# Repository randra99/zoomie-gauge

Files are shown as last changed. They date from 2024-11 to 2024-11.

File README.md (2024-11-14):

# Zoomie Gauge
Zoomie Gauge was created as an effective DIY way of monitoring engine vitals, with the idea that visible alerts are most effective at preventing engine damage as compared to traditional gauges in motorsport applications.

Gauge GIF Gauge GIF

At the moment this has been developed and tested on an NC Mazda MX-5/Miata, however, given the right CAN frames this can be extended to virtually any CAN enabled vehicle.

## Hardware needed:
 - [Arduino UNO board](https://store.arduino.cc/products/arduino-uno-rev3)
 - [1.28 inch LCD Module](https://www.waveshare.com/wiki/1.28inch_LCD_Module)
   - Wiring instructions can be found on the same page
 - [DC to DC Buck Converter](https://www.amazon.co.uk/gp/product/B0823P6PW6/ref=ppx_yo_dt_b_search_asin_title?ie=UTF8&th=1)
 - [MCP2515 CAN Bus Module](https://www.amazon.co.uk/gp/product/B086TXSFD8/ref=ppx_yo_dt_b_search_asin_title?ie=UTF8&th=1)
   - Wiring instructions can be found [here](https://github.com/autowp/arduino-mcp2515)
 - [Bosch PST-F 1 Sensor](https://www.bosch-motorsport.com/content/downloads/Raceparts/en-GB/54249355.html)
   - Consult the data sheet for wiring 

### Nice to haves:
 - [Proto Shield](https://thepihut.com/products/arduino-proto-shield-dev-board-2-0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)
   - This will make splicing the connections for both the CAN Bus module and LCD module is a lot easier.
   - Furthermore, as the Arduino cannot measure resistance out of the box, a small circuit is required utilising a 4.7K ohm resistor to allow computation of the resistance based on voltage. Instructions [here](https://projecthub.arduino.cc/xristos_xatz/ohm-meter-with-arduino-uno-5576cd).

## STL Files
Currently included in `stl-files` is the stl of the screen mount, this will make it easier to mount the screen to the desired surface using double-sided tape. The centre is left empty to allow placing over an existing gauge once the needle is removed.

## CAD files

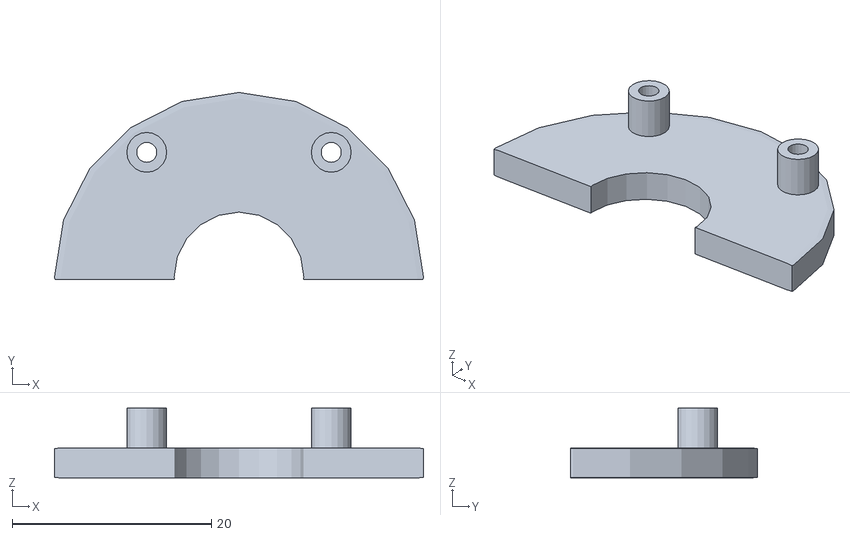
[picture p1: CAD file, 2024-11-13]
stl-files/DisplayMount.stl
37.0 x 18.8 x 7.00

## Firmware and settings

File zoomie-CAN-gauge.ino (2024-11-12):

#include "SPI.h"
#include "Adafruit_GFX.h"
#include "Adafruit_GC9A01A.h"
#include "CAN.h"
#include <math.h>

// Define pins for display interface. You'll probably need to edit this for
// your own needs:

#if defined(ARDUINO_SEEED_XIAO_RP2040)

// Pinout when using Seed Round Display for XIAO in combination with
// Seeed XIAO RP2040. Other (non-RP2040) XIAO boards, any Adafruit Qt Py
// boards, and other GC9A01A display breakouts will require different pins.
#define TFT_CS D1 // Chip select
#define TFT_DC D3 // Data/command
#define TFT_BL D6 // Backlight control

#else // ALL OTHER BOARDS - EDIT AS NEEDED

// Other RP2040-based boards might not have "D" pin defines as shown above
// and will use GPIO bit numbers. On non-RP2040 boards, you can usually use
// pin numbers silkscreened on the board.
#define TFT_DC  7
#define TFT_CS 10
// If display breakout has a backlight control pin, that can be defined here
// as TFT_BL. On some breakouts it's not needed, backlight is always on.

#endif

// Display constructor for primary hardware SPI connection -- the specific
// pins used for writing to the display are unique to each board and are not
// negotiable. "Soft" SPI (using any pins) is an option but performance is
// reduced; it's rarely used, see header file for syntax if needed.
Adafruit_GC9A01A tft(TFT_CS, TFT_DC);

int water_temp = 0;
int oil_pressure = 0;
int oil_temp = 0;
int rpm = 0;

int last_water_temp = -1;
int last_oil_pressure = -1;
int last_oil_temp = -1;

int no_water_temp = 0;
bool no_rpm = true;
bool warning_on = false;

void write_num(int x, int y, int size, int num, int colour=WHITE)
{
  if(num < 0)
  {
    x=x-15;
    if(num < -99)
      x=x-15;
    if(num > -10)
      x=x+15;
  }
  else
  {
    if(num < 10)
      x=x+15;
    if(num > 99)
      x=x-15;
  }
  tft.setTextColor(colour);
  tft.setCursor(x,y);
  tft.setTextSize(size);
  tft.println(String(num));
}

void write_none(int x, int y, int size, int colour=WHITE)
{
  tft.setTextColor(colour);
  tft.setCursor(x,y);
  tft.setTextSize(size);
  tft.println("XX");
}

void write_values(int water_temp, int oil_pressure, int oil_temp, bool force_write=false)
{
  if(last_water_temp!=water_temp || force_write)
  {
    tft.fillRect(92, 13, 70, 35, BLACK);
    write_num(92,13,5,water_temp);
    last_water_temp = water_temp;
  }
  if(last_oil_pressure!=oil_pressure || force_write)
  {
    tft.fillRect(125, 102, 70, 35, BLACK);
    write_num(125,102,5,oil_pressure);
    last_oil_pressure = oil_pressure;
  }
  if(last_oil_temp!=oil_temp || force_write)
  {
    tft.fillRect(90, 188, 70, 35, BLACK);
    write_num(90,188,5,oil_temp);
    last_oil_temp = oil_temp;
  }
}

void write_text(int x, int y, int size, char* text, int colour=WHITE)
{
  tft.setTextColor(colour);
  tft.setCursor(x,y);
  tft.setTextSize(size);
  tft.write(text);
}

void display_water_warning()
{
  tft.fillScreen(RED);
  write_text(50,60,5,"WATER");
  write_text(65,100,5,"TEMP");
  write_num(90,150,5,water_temp);
  delay(200);
  tft.fillScreen(WHITE);
  write_text(50,60,5,"WATER", BLACK);
  write_text(65,100,5,"TEMP", BLACK);
  write_num(90,150,5,water_temp, BLACK);
  delay(200);
}

void display_no_water_temp_warning()
{
  tft.fillScreen(RED);
  write_text(90,60,5,"NO");
  write_text(50,100,5,"WATER");
  write_text(65,150,5,"TEMP");
  delay(200);
  tft.fillScreen(WHITE);
  write_text(90,60,5,"NO", BLACK);
  write_text(50,100,5,"WATER", BLACK);
  write_text(65,150,5,"TEMP", BLACK);
  delay(200);
}

void display_oil_press_warning()
{
  tft.fillScreen(RED);
  write_text(80,60,5,"OIL");
  write_text(50,100,5,"PRESS");
  write_num(90,150,5,oil_pressure);
  delay(200);
  tft.fillScreen(WHITE);
  write_text(80,60,5,"OIL", BLACK);
  write_text(50,100,5,"PRESS", BLACK);
  write_num(105,150,5,oil_pressure, BLACK);
  delay(200);
}

void display_oil_temp_warning()
{
  tft.fillScreen(RED);
  write_text(80,60,5,"OIL");
  write_text(60,100,5,"TEMP");
  write_num(90,150,5,oil_temp);
  delay(200);
  tft.fillScreen(WHITE);
  write_text(80,60,5,"OIL", BLACK);
  write_text(60,100,5,"TEMP", BLACK);
  write_num(90,150,5,oil_temp, BLACK);
  delay(200);
}

void draw_info_screen()
{
  tft.fillScreen(BLACK);

  tft.drawCircle(120,120, 119, RED);
  write_text(60,60,2,"WATER TEMP");
  tft.drawLine(0, 85, 240, 85, WHITE);
  write_text(10,100,2,"OIL");
  write_text(10,120,2,"PRESS");
  tft.drawLine(0, 155, 250, 155, WHITE);
  write_text(75,162,2,"OIL TEMP");
  write_values(water_temp,oil_pressure,oil_temp,true);
}

void screen_setup()
{
  tft.begin();

  tft.setRotation(1);

  #if defined(TFT_BL)
  pinMode(TFT_BL, OUTPUT);
  digitalWrite(TFT_BL, HIGH); // Backlight on
  #endif // end TFT_BL

  draw_info_screen();
}

void setup() {
  screen_setup();

  Serial.begin(9600);
  while (!Serial);

  Serial.println("CAN Receiver");

  CAN.setClockFrequency(8E6);
  // start the CAN bus at 500 kbps
  while(!CAN.begin(500E3)) {
    tft.fillScreen(WHITE);
    Serial.println("Starting CAN failed!");
    tft.fillScreen(CYAN);
  }
}

void read_bosch_sensor()
{
  int raw = 0;
  int Vin = 5;
  float Vout = 0;
  float R1 = 4700;
  float R2 = 0;
  float buffer = 0;

  float pressure_voltage = analogRead(A0) * 5 / 1024.0;
  oil_pressure = round(36.25 * pressure_voltage - 18.125);
  Serial.print("Pressure :");
  Serial.println(oil_pressure);

  raw = analogRead(A1);
  if(raw){
    R2 = R1 / ((Vin / ( raw * 5 / 1024.0) ) - 1);
    oil_temp = round( 279 -33.9 * log(R2));

    Serial.print("Temp: ");
    Serial.println(oil_temp);

  }
}

void read_can_water_temp()
{
  int packetSize;
  unsigned long StartTime = millis();
  unsigned long CurrentTime = millis();
  do{
    packetSize = CAN.parsePacket();
    CurrentTime = millis();
  }while(!(packetSize && CAN.packetId()==0x240) && (CurrentTime - StartTime < 1000));

  if(CAN.packetId()==0x240)
  {
    int byteno = 0;
    int len = CAN.available();
    for(int i = 0; i < len; i++)
    {
      if(i == 1)
      {
          water_temp = CAN.read()-40;
          Serial.println("Water temp: " + water_temp);
          write_values(water_temp,oil_pressure,oil_temp);
      }
      else
        CAN.read();
    }
    no_water_temp = 0;
  }
  else
    no_water_temp++;
}

void read_can_rpm()
{
  int packetSize;
  unsigned long StartTime = millis();
  unsigned long CurrentTime = millis();
  do{
    packetSize = CAN.parsePacket();
    CurrentTime = millis();
  }while(!(packetSize && CAN.packetId()==0x201) && (CurrentTime - StartTime < 1000));

  if(CAN.packetId()==0x201)
  {
    byte rpm_byte0, rpm_byte1;
    int byteno = 0;
    int len = CAN.available();
    for(int i = 0; i < len; i++)
    {
      if(i == 0)
          rpm_byte0 = CAN.read();
      if(i == 1)
          rpm_byte1 = CAN.read();
      else
        CAN.read();

      rpm = ((rpm_byte0 << 8) + rpm_byte1) / 4;      
      Serial.print("RPM:");
      Serial.println(rpm);  
    }
    no_rpm = false;
  }
  else
    no_rpm = true;
}

void loop(void) {
  read_can_water_temp();
  read_can_rpm();
  read_bosch_sensor();
  delay(100);

  if(((no_rpm || (rpm > 0 && rpm < 1000)) && oil_pressure < 10) || (rpm > 3000 && oil_pressure < 20))
  {
    display_oil_press_warning();
    warning_on = true;
  }
  else if(oil_temp > 120 || oil_temp < -100)
  {
    display_oil_temp_warning();
    warning_on = true;
  }
  else if(no_water_temp > 10)
  {
    display_no_water_temp_warning();
    warning_on = true;
  }
  else if(water_temp > 115)
  {
    display_water_warning();
    warning_on = true;
  }
  else
  {
    if(warning_on)
    {
      draw_info_screen();
      warning_on = false;
    }
    else
    {
      write_values(water_temp,oil_pressure,oil_temp);
    }
  }
}

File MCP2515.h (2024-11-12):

// Copyright (c) Sandeep Mistry. All rights reserved.
// Licensed under the MIT license. See LICENSE file in the project root for full license information.

#ifndef ARDUINO_ARCH_ESP32

#ifndef MCP2515_H
#define MCP2515_H

#include <SPI.h>

#include "CANController.h"

#define MCP2515_DEFAULT_CLOCK_FREQUENCY 16e6

#if defined(ARDUINO_ARCH_SAMD) && defined(PIN_SPI_MISO) && defined(PIN_SPI_MOSI) && defined(PIN_SPI_SCK) && (PIN_SPI_MISO == 10) && (PIN_SPI_MOSI == 8) && (PIN_SPI_SCK == 9)
// Arduino MKR board: MKR CAN shield CS is pin 3, INT is pin 7
#define MCP2515_DEFAULT_CS_PIN          3
#define MCP2515_DEFAULT_INT_PIN         7
#else
#define MCP2515_DEFAULT_CS_PIN          3
#define MCP2515_DEFAULT_INT_PIN         2
#endif

class MCP2515Class : public CANControllerClass {

public:
  MCP2515Class();
  virtual ~MCP2515Class();

  virtual int begin(long baudRate);
  virtual void end();

  virtual int endPacket();

  virtual int parsePacket();

  virtual void onReceive(void(*callback)(int));

  using CANControllerClass::filter;
  virtual int filter(int id, int mask);
  using CANControllerClass::filterExtended;
  virtual int filterExtended(long id, long mask);

  virtual int observe();
  virtual int loopback();
  virtual int sleep();
  virtual int wakeup();

  void setPins(int cs = MCP2515_DEFAULT_CS_PIN, int irq = MCP2515_DEFAULT_INT_PIN);
  void setSPIFrequency(uint32_t frequency);
  void setClockFrequency(long clockFrequency);

  void dumpRegisters(Stream& out);

private:
  void reset();

  void handleInterrupt();

  uint8_t readRegister(uint8_t address);
  void modifyRegister(uint8_t address, uint8_t mask, uint8_t value);
  void writeRegister(uint8_t address, uint8_t value);

  static void onInterrupt();

private:
  SPISettings _spiSettings;
  int _csPin;
  int _intPin;
  long _clockFrequency;
};

extern MCP2515Class CAN;

#endif

#endif
